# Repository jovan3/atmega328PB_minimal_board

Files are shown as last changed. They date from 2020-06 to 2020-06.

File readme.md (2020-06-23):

# Atmega328PB-AU Minimal board

A Kicad project for an Atmega328PB-AU minimal board. I got a few of these microcontrollers and I read that they have some interesting features that Atmega328Ps don't have, such as additional USART, SPI, Timers, etc.

## Programming

There's a 10-pin AVR ICSP header. I used USBASP with Arduino to burn an Arduino bootloader and flash a sketch. I used [this](https://github.com/watterott/ATmega328PB-Testing) github project to get the Atmega328PB board definition files working and used the "Atmega328PB Internal Clock" with the 8MHz option to flash the bootloader. The microcontroller board has a crystal oscillator. If it's populated with a 16MHz crystal, for example, the microcontroller can be programmed to use that. You can use any of the six exposed microcontroller pins (23-26, 30, 31) to connect an LED for example, to test with a Blink Hello World program.

## Preview

Here's a 3D rendering of the board viewed from above, so you can see how it looks like without importing the project in Kicad:

<p align="center">
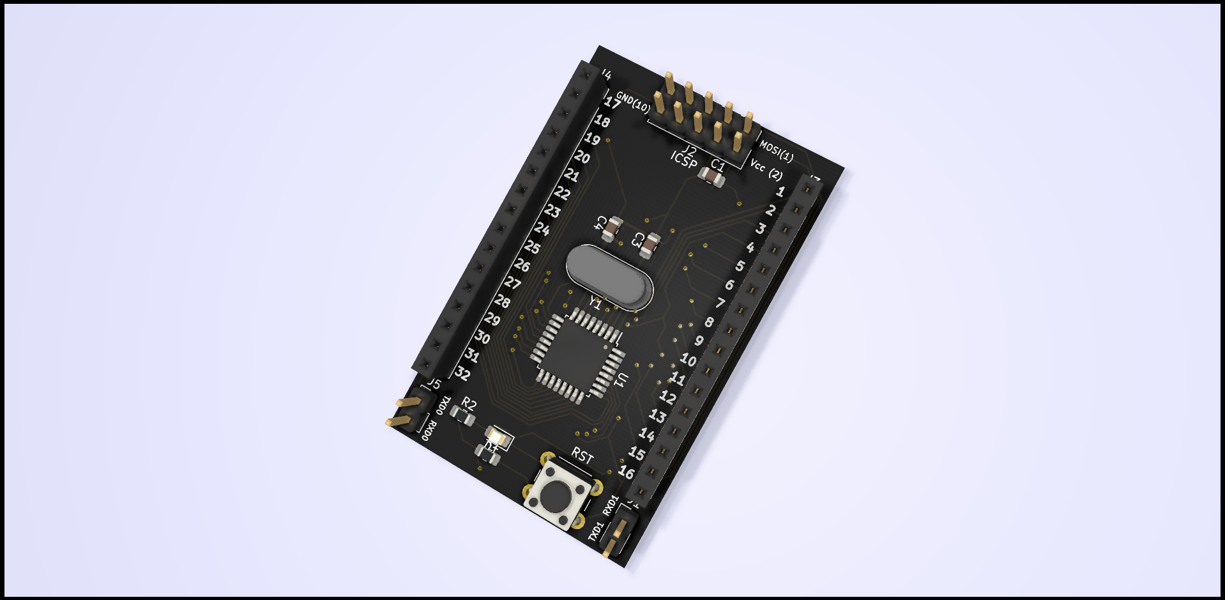
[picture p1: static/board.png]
  
</p>

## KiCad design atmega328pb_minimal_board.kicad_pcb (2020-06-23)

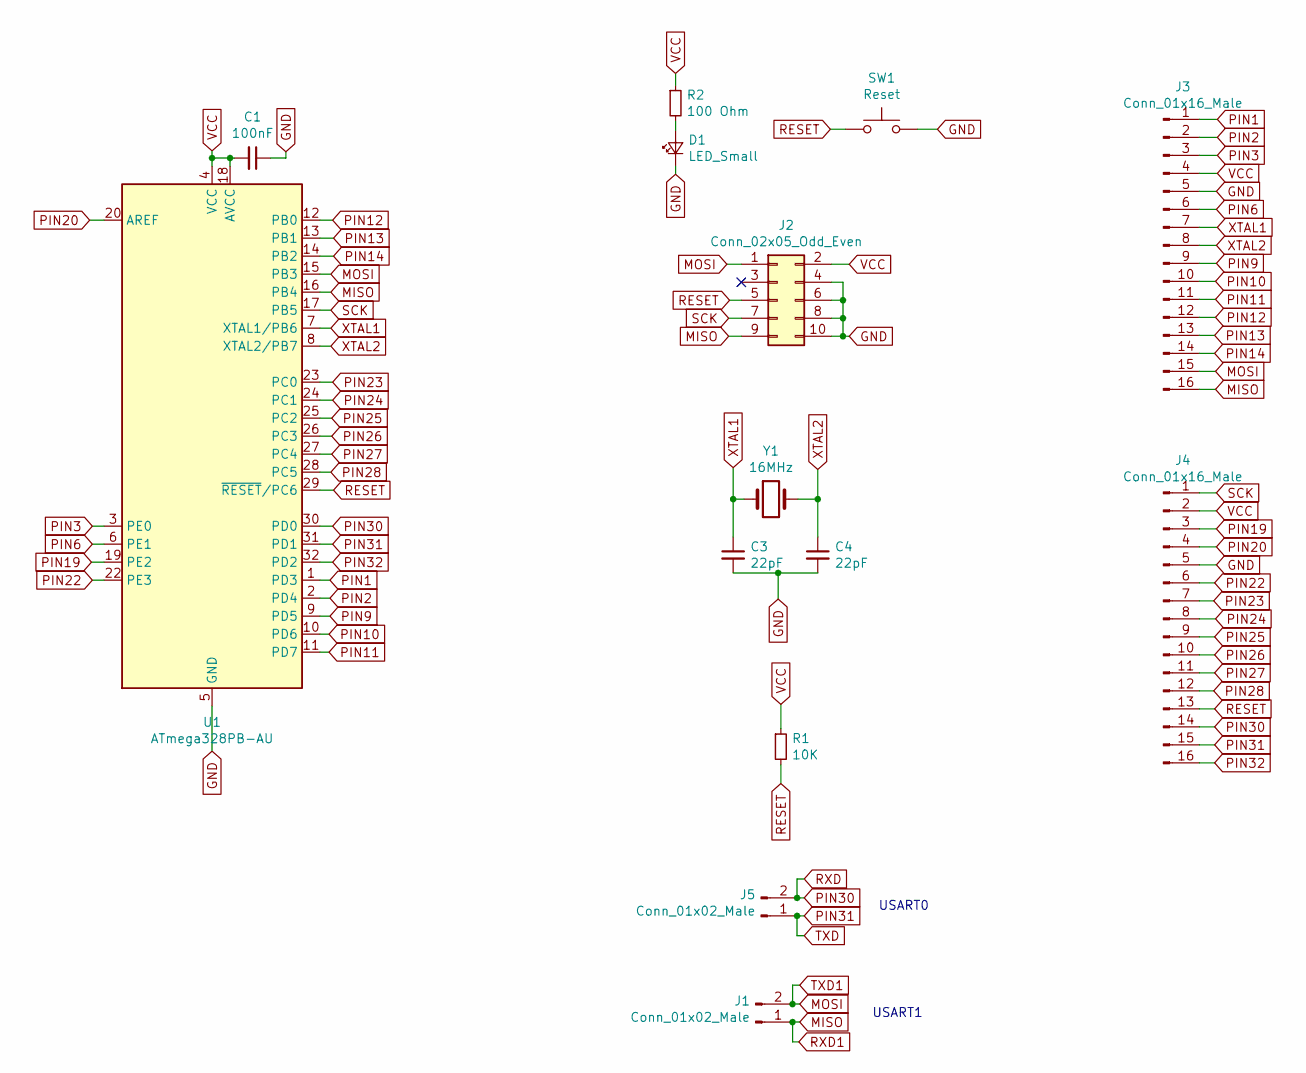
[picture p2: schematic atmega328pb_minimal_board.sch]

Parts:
C1: 100nF; C_0805_2012Metric_Pad1.15x1.40mm_HandSolder
C3, C4: 22pF; C_0805_2012Metric_Pad1.15x1.40mm_HandSolder
D1: LED_Small; LED_0805_2012Metric_Pad1.15x1.40mm_HandSolder
J1, J5: Conn_01x02_Male; PinHeader_1x02_P2.54mm_Vertical
J2: Conn_02x05_Odd_Even; PinHeader_2x05_P2.54mm_Vertical
J3, J4: Conn_01x16_Male; PinSocket_1x16_P2.54mm_Vertical
R1: 10K; R_0805_2012Metric_Pad1.15x1.40mm_HandSolder
R2: 100 Ohm; R_0805_2012Metric_Pad1.15x1.40mm_HandSolder
SW1: Reset; SW_PUSH_6mm_H5mm
U1: ATmega328PB-AU; TQFP-32_7x7mm_P0.8mm
Y1: 16MHz; Crystal_HC49-4H_Vertical

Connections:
GND: C1.1, C3.2, C4.2, D1.1 (K), J2.4, J2.6, J2.8, J2.10, J3.5, J4.5, SW1.2, U1.5 (GND), U1.21 (GND); also elsewhere on the board
MISO: J1.1, J2.9, J3.16, U1.16 (PB4)
MOSI: J1.2, J2.1, J3.15, U1.15 (PB3)
unnamed: D1.2 (A), R2.2
PIN1: J3.1, U1.1 (PD3)
PIN2: J3.2, U1.2 (PD4)
PIN3: J3.3, U1.3 (PE0)
PIN6: J3.6, U1.6 (PE1)
PIN9: J3.9, U1.9 (PD5)
PIN10: J3.10, U1.10 (PD6)
PIN11: J3.11, U1.11 (PD7)
PIN12: J3.12, U1.12 (PB0)
PIN13: J3.13, U1.13 (PB1)
PIN14: J3.14, U1.14 (PB2)
PIN19: J4.3, U1.19 (PE2)
PIN20: J4.4, U1.20 (AREF)
PIN22: J4.6, U1.22 (PE3)
PIN23: J4.7, U1.23 (PC0)
PIN24: J4.8, U1.24 (PC1)
PIN25: J4.9, U1.25 (PC2)
PIN26: J4.10, U1.26 (PC3)
PIN27: J4.11, U1.27 (PC4)
PIN28: J4.12, U1.28 (PC5)
PIN30: J4.14, J5.2, U1.30 (PD0)
PIN31: J4.15, J5.1, U1.31 (PD1)
PIN32: J4.16, U1.32 (PD2)
RESET: J2.5, J4.13, R1.2, SW1.1, U1.29 (~RESET~/PC6); also elsewhere on the board
SCK: J2.7, J4.1, U1.17 (PB5)
VCC: C1.2, J2.2, J3.4, J4.2, R1.1, R2.1, U1.4 (VCC), U1.18 (AVCC)
XTAL1: C3.1, J3.7, U1.7 (XTAL1/PB6), Y1.1
XTAL2: C4.1, J3.8, U1.8 (XTAL2/PB7), Y1.2

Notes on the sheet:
USART0
USART1

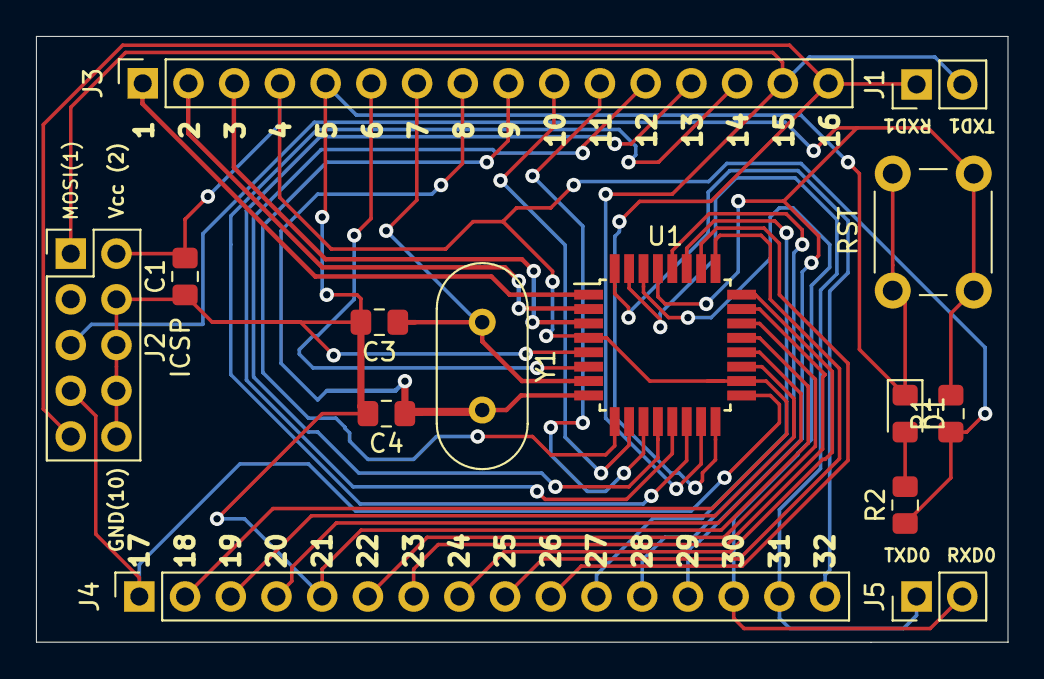
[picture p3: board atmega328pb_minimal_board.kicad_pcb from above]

Board: 2 copper layers, 54.0 x 33.7 mm, 14 parts (0 on the bottom side), 31 nets.

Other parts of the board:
RST: Reset; SW_PUSH_6mm_H5mm

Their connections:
GND: RST.2; also elsewhere on the board
RESET: RST.1; also elsewhere on the board

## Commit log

2019-08-23 change board layout
    [atmega328pb_minimal_board.kicad_pcb]
2019-08-23 add reset button, two usart headers and an LED
    [atmega328pb_minimal_board.kicad_pcb, atmega328pb_minimal_board.sch]
2019-08-28 change 2 1x16 male pin headers to female connectors
    [atmega328pb_minimal_board.kicad_pcb, atmega328pb_minimal_board.sch]
2019-08-28 add some pin labels
    [atmega328pb_minimal_board.kicad_pcb]
2019-09-11 add board 3d rendering image for github
2019-09-11 remove old gerber and pdf files
    [atmega328pb_minimal_board-F_Cu.gbr]
2020-06-23 update front silkscreen around the ICSP. Update docs.
    [atmega328pb_minimal_board.kicad_pcb]
